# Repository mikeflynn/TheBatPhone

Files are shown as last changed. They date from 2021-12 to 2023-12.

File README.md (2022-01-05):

# The Bat Phone

A "working" replica of the 1960s Bat Phone.

## Demo

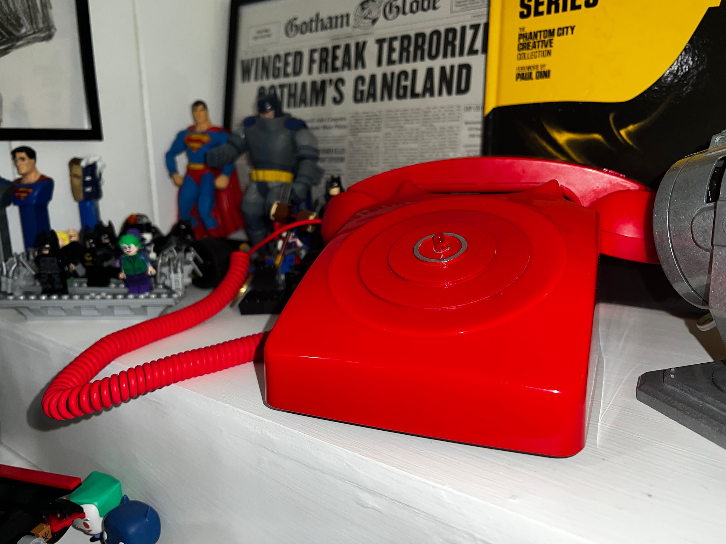
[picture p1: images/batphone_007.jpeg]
My Bat Phone (https://www.youtube.com/watch?v=4xc30-9TLgI)


(Click the picture above for a short YouTube video demo.)

I have a small Batman collection and thought it would be cool to have a replica of the Bat Phone from the Adam West series. This version "rings" semi-randomly throughout the day by flashing it's red light. If you pick it up while it's ringing you can hear a clip from the show, otherwise you get a dial tone.

## Parts

**Phone Base:** 

[I found this model on Amazon](https://www.amazon.com/dp/B098RYL855/ref=cm_sw_em_r_mt_dp_VS4C6HZS7EKWGHEA6X09?_encoding=UTF8&psc=1) which was cheap, seemed easy to remove the parts I didn't want, and was a great classic shape. I removed the dial and all electronics but the reciever switch.

**Dial Insert / LED Housing:** 

Designed and 3D printed myself. [Here is the STL file](models/bat_phone_insert_v3.stl).

**On/Off Switch & Light:** 

A momentary button with LED I had in my workshop ([available at Adafruit](https://www.adafruit.com/product/1439)). The one I have in place is not ideal, but it works. 

**Red Light:** 

Standard LED light you can get anywhere.

**Reciever Switch:** 

Repurosed from the phone circuitry. I orignally had a cheap button under the reciever lever, but it was pushing back on the reciever too much, even after trying to add weight to the reciever. I removed the switch in favor of the switch from the phone and it works great, but the code is a little wonky because of how the switch worked.

**Reciever:** 

I happened to have a novelty phone reciever that terminated in a minijack that I recievved as a corporate gift years ago and I used that. [You can find something simliar on Amazon.](https://www.amazon.com/CellCase-Telephone-Microphone-Cellphone-Smartphone/dp/B08Y8J5LK5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)

**Brains:** 

Overkill, but I had a spare Raspberry Pi 3 B in my workshop and since that has a minijack audio output already, it was what I used. A better option would be a small Ardiuno (though with enough memory for the audio clips) and an audio out interface. If you do use a Raspberry Pi, I have included a [setup.sh](setup.sh) file that includes the commands needed to run to get the code I have working.

**Paint:**

[Rust-Oleum Enamel Cherry Red](https://www.amazon.com/Rust-Oleum-248568-Stops-12-Ounce-Cherry/dp/B003ES43D0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) proved to be a great color match with the phone body, and I used [a chrome paint pen](https://www.amazon.com/gp/product/B09C1SRRBW/ref=ppx_yo_dt_b_asin_title_o03_s00?ie=UTF8&psc=1) to add the detail around the LED.

## Code

In it's current state the code is quickly written Python, but it works and I might go back and refine it. There are two parts: [batphone.py](batphone.py) and [shutdown.py](shutdown.py)

_batphone.py_ is the full service that handles the "phone" functionality. _shutdown.py_ is just a small script that watches a specific GPIO script for a signal to properly shutdown the Pi.

## Sound

You can use any files for sound, but I do have my collection of wav files that I used for source in [wavs/source](wavs/source/) and what I came up with in [wavs/answers](wavs/answers). I spent very little time on this aspect so if you have better ideas or any skill at audio editing at all, I would _love_ to hear what you came up with.

## Build Photos

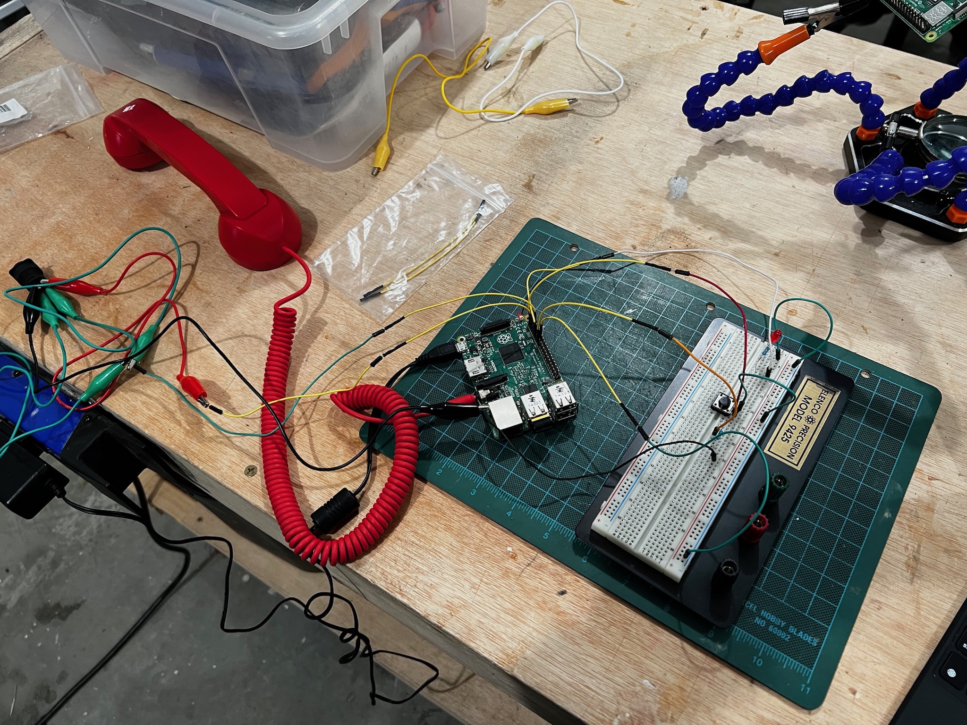
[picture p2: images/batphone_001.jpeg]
Initial Breadboarding


Initial breadboarding.

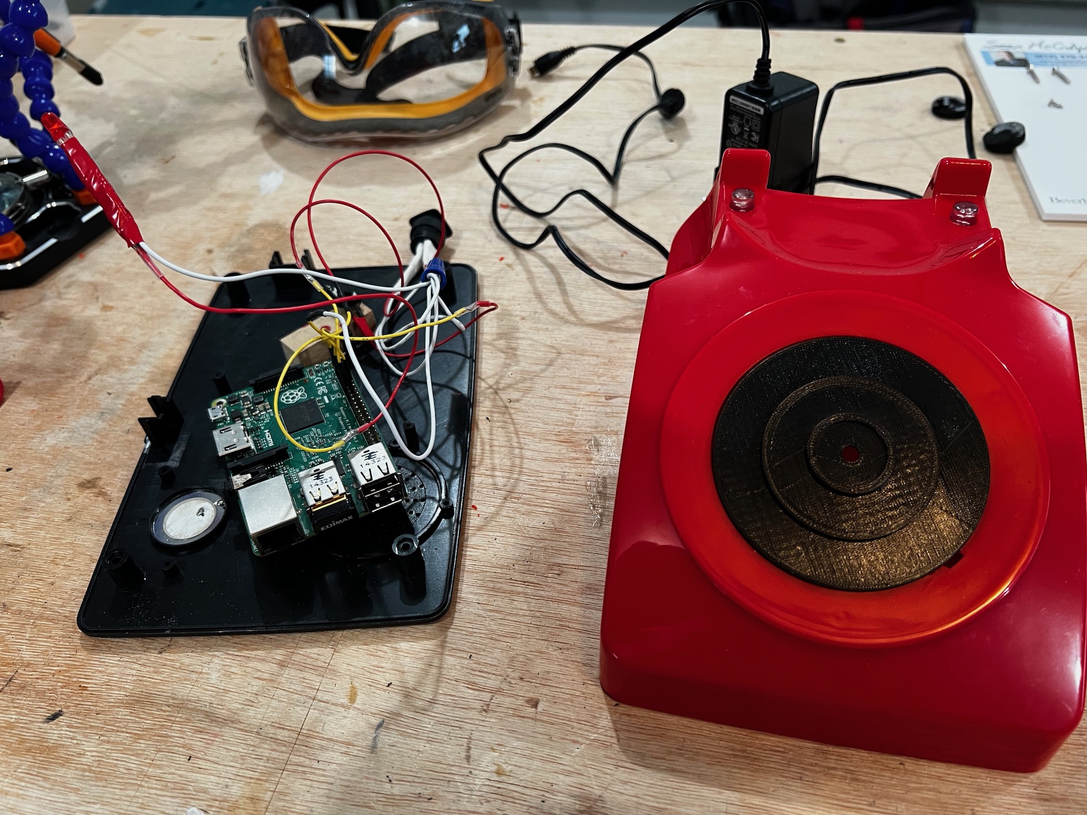
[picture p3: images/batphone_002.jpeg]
Mounting in the case and testing a 3D printed insert.


Mounting in the case and testing a 3D printed insert.

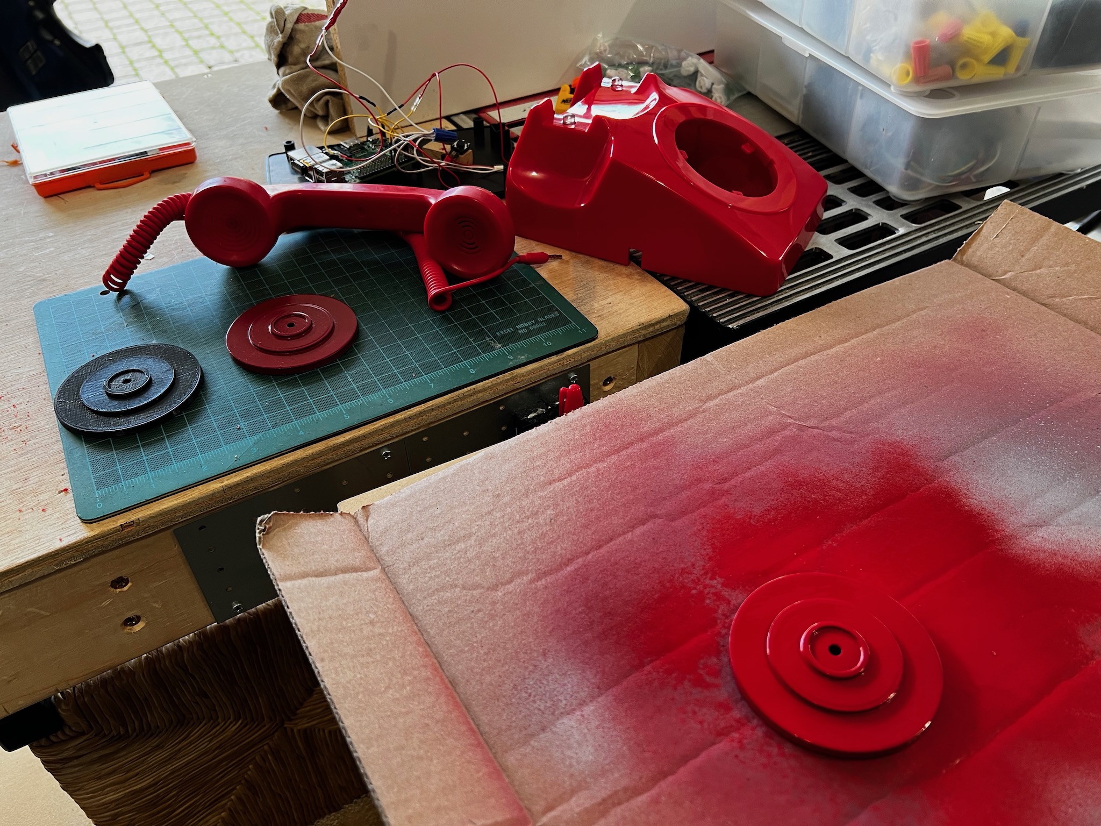
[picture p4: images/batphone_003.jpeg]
Painting v3 of the LED insert.


Paiting v3 of the LED insert (once I found the _right_ "Cherry Red" color).

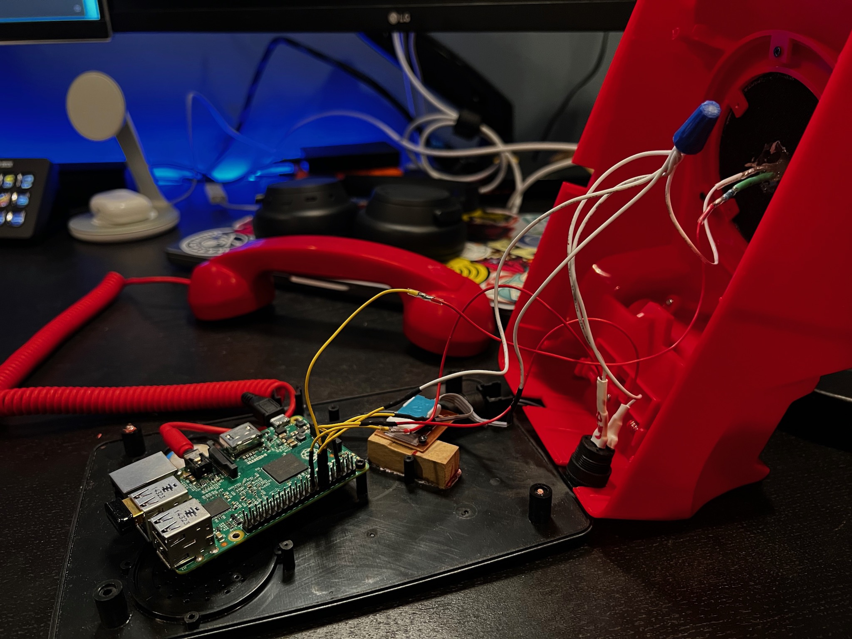
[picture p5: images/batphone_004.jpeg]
The last minute switch to the phone reciever switch.


The last minute switch to the phone reciever switch!

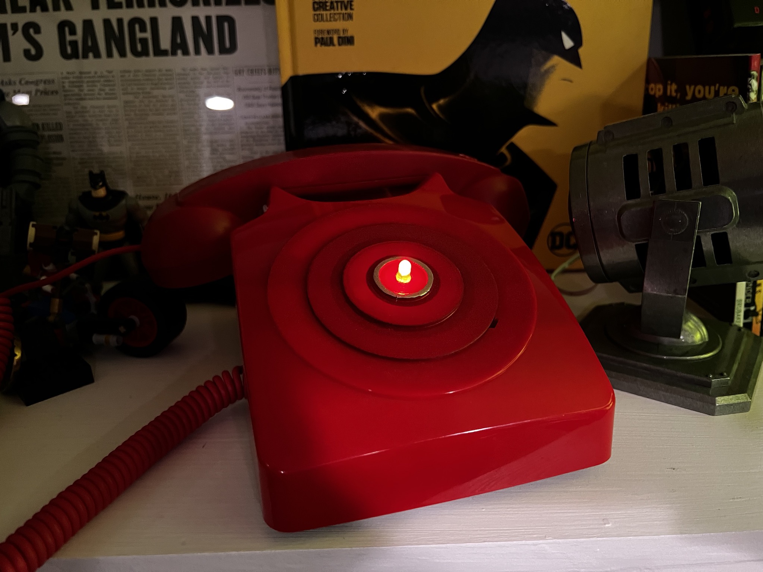
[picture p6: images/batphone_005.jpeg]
Ringing


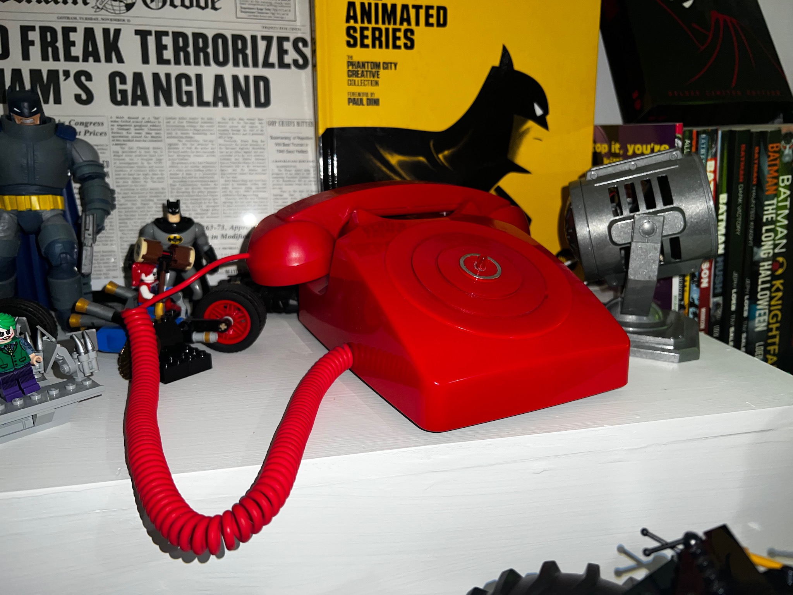
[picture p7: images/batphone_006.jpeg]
On the shelf


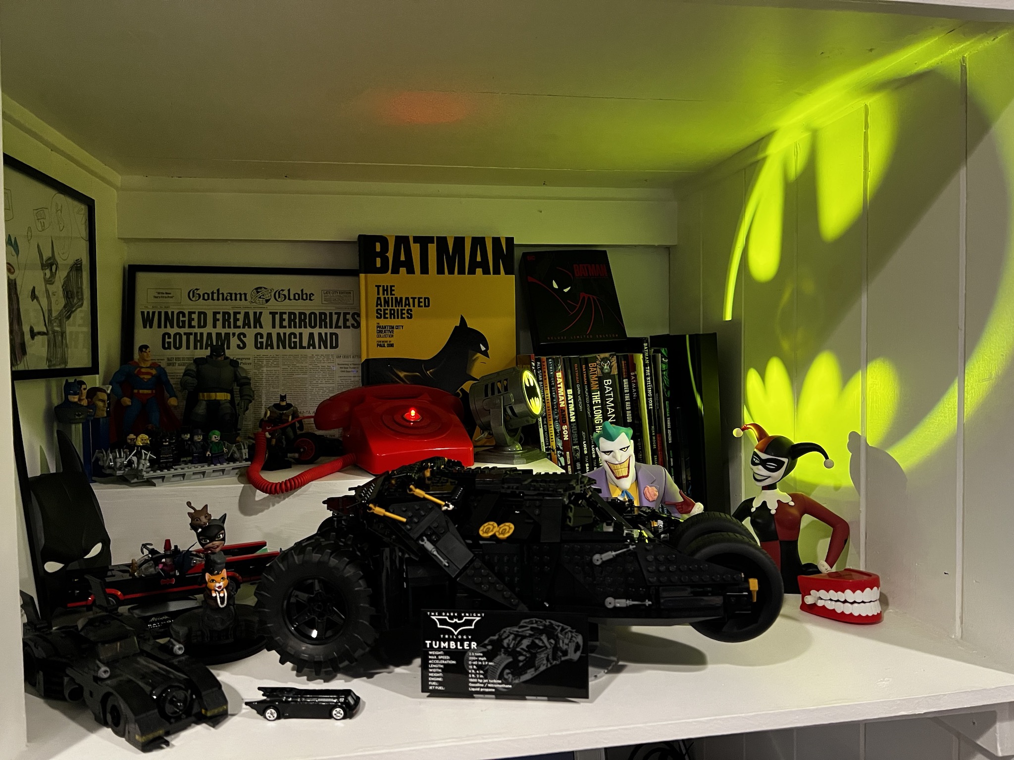
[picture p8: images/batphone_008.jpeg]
Full view of the Batman shelf


Final display photos.

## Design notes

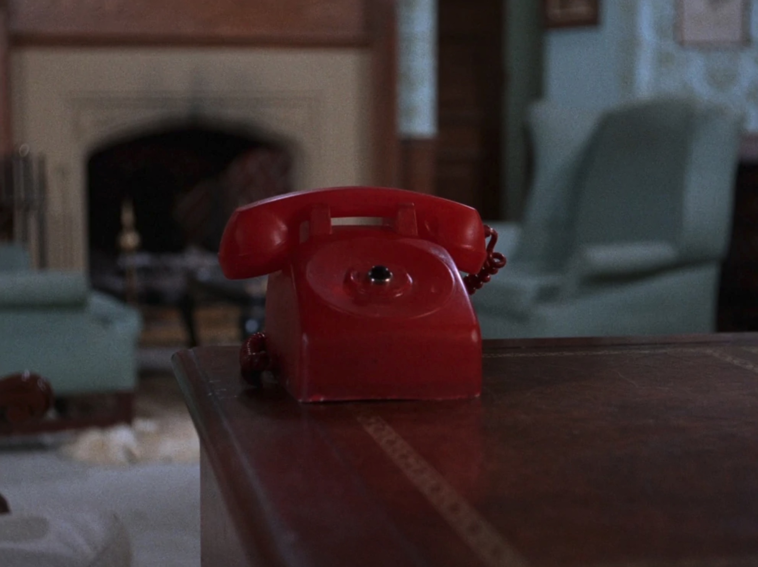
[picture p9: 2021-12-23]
images/batphone_screen.jpg

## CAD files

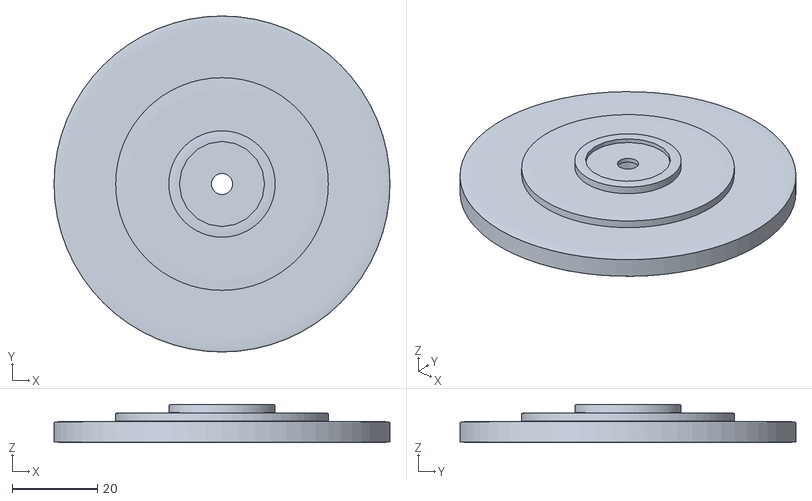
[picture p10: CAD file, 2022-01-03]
models/bat_phone_insert_v3.stl
79.0 x 79.0 x 9.00

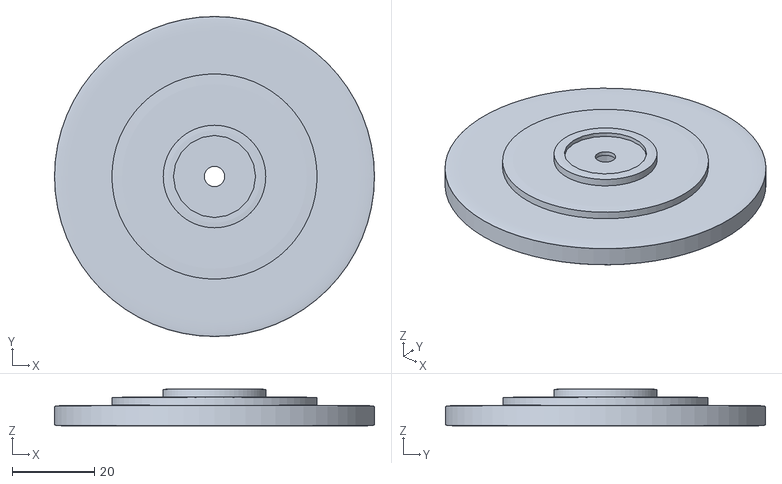
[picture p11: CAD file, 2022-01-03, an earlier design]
models/bat_phone_insert_v2.stl
78.0 x 78.0 x 9.00

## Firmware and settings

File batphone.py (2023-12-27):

import sched, random
from gpiozero import LED, Button
from time import sleep, time
from pygame import mixer
from signal import pause
from os import listdir
from os.path import isfile, join
import subprocess

# Init

devMode = False

reciever = Button(18)
led = LED(17)
statusLed = LED(22)

onTheHook = True
isRinging = False
lastPickup = 0
pickupCount = 0

wavPath = '/opt/batphone/wavs/'
wavFiles = [f for f in listdir(wavPath + 'answers/') if isfile(join(wavPath + 'answers/', f))]

cron = sched.scheduler(time, sleep)
mixer.init()

# Functions

def getRingInterval():
    return 30

def log(msg):
    if devMode:
        print(msg)

def hungUp():
    global onTheHook
    log("Hung Up")
    onTheHook = True

def pickedUp():
    log("Picked Up")
    global onTheHook
    global isRinging
    global lastPickup
    global pickupCount
    global devMode

    onTheHook = False

    if lastPickup < (time() - 5):
        pickupCount = 0
    else:
        pickupCount += 1

    lastPickup = time()
    log("Pickup Count: " + str(pickupCount))

    if pickupCount == 3: # 3 clicks => Schedule a ring.
        log("Toggle Dev Mode")
        play(wavPath + 'system/dev_mode_toggle.wav')
        if devMode:
            devMode = False
        else:
            devMode = True
    elif pickupCount == 5:
        log("Shutting down...")
        play(wavPath + 'system/shutdown.wav')
        subprocess.call(['shutdown', '-h', 'now'], shell=False)
    elif isRinging == True:
        isRinging = False
        sleep(1)
        play(None)
    elif pickupCount == 0:
        play(wavPath + 'system/dialtone.wav')

def shouldRing():
    """Checks if the phone should ring or not."""
    global devMode

    onSchedule = False
    if devMode:
        onSchedule = True
    else:
        if random.randint(0, 100) % 4 == 0:
            onSchedule = True

    return onSchedule and onTheHook and not(isRinging)

def ring(job):
    """Rings the phone by flashing the light."""
    global isRinging
    log("Possibly ringining..")
    cron.enter(getRingInterval(), 1, ring, (job,))
    if shouldRing():
        log("Ringing!")
        isRinging = True
        for x in range(0, 4):
            for x in range(0, 20):
                led.toggle()
                sleep(0.1)
            if onTheHook == False:
                break;
            sleep(3)
        isRinging = False

def play(file):
    """Batman picks up; Play the audio."""
    log("Playing audio...")
    if file is None:
        global wavFiles
        answer = wavPath + 'answers/' + random.choice(wavFiles)
        log(answer)
        sound = mixer.Sound(answer)
    else:
        sound = mixer.Sound(file)
    sound.set_volume(0.75)
    sound.play()

# Main

statusLed.on()
play(wavPath + 'system/batman_theme.wav')

reciever.when_pressed = pickedUp # Weird flipped logic because of the switch I hacked out of the original phone.
reciever.when_released = hungUp

cron.enter(10, 1, ring, (cron,)) # After boot, ring right away for quick testing.
cron.run()

pause()

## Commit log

2022-01-03 Small tweaks and added stl files.
    [bat_phone_insert_v2.stl, bat_phone_insert_v3.stl]
2022-01-04 Updated python service logic to work with new switch I hacked in from the original phone.
2023-12-27 Updated 3 click shortcut to toggle dev mode.
    [batphone.py]
